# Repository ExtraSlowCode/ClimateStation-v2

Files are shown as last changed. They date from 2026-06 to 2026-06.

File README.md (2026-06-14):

# ClimateStation v2

A lightweight IoT climate monitor running on a Raspberry Pi Pico W. Reads temperature, humidity, and light level, then serves a terminal-aesthetic dashboard on the local network. No cloud dependency.

Soldered onto matrix board and housed in a custom 3D-printed case — designed to sit cleanly on a desk or shelf as a permanent fixture.

Successor to [ClimateStation](https://github.com/ExtraSlowCode/ClimateStation/tree/main) — reworked for local hosting, removed DataCake dependency.

---

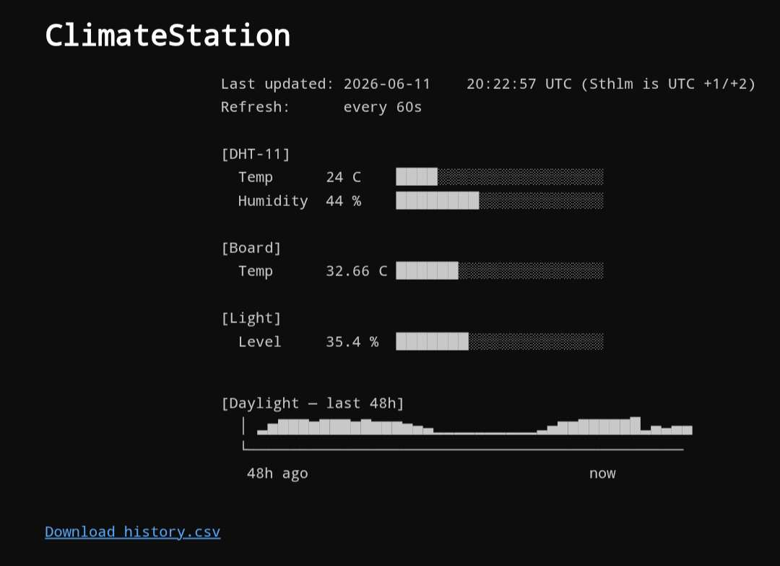
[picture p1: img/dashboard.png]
ClimateStation v2 dashboard

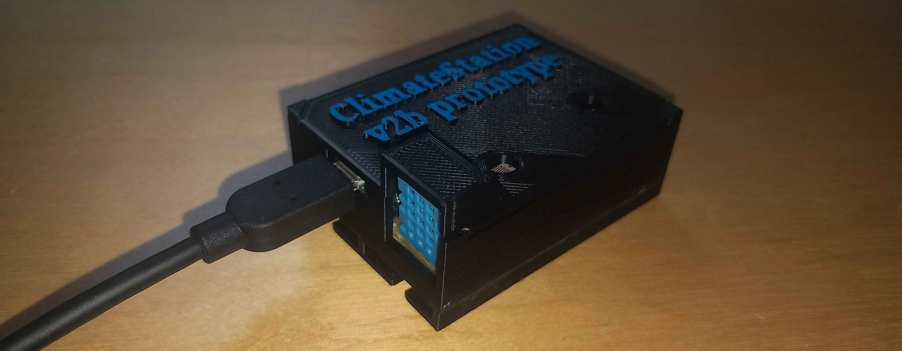
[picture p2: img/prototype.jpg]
ClimateStation v2 device


---

## Hardware

| Component | Purpose |
|---|---|
| Raspberry Pi Pico W | Microcontroller |
| DHT-11 | Temperature + humidity |
| Photo resistor (CdS 5mm) | Light level |
| On-board sensor (ADC4) | Secondary temperature |
| Green LED | Activity indicator |
| Matrix board | Permanent soldered assembly |

## Build

The circuit is soldered directly onto matrix board rather than using a breadboard, keeping the assembly compact and reliable. A custom case designed in TinkerCAD houses everything and is printed in standard PLA on an Ender 3.

Print settings:

- Filament: 1.75mm PLA
- Default supports
- Standard quality settings

The case design is included in `/case` as a `.stl` file.

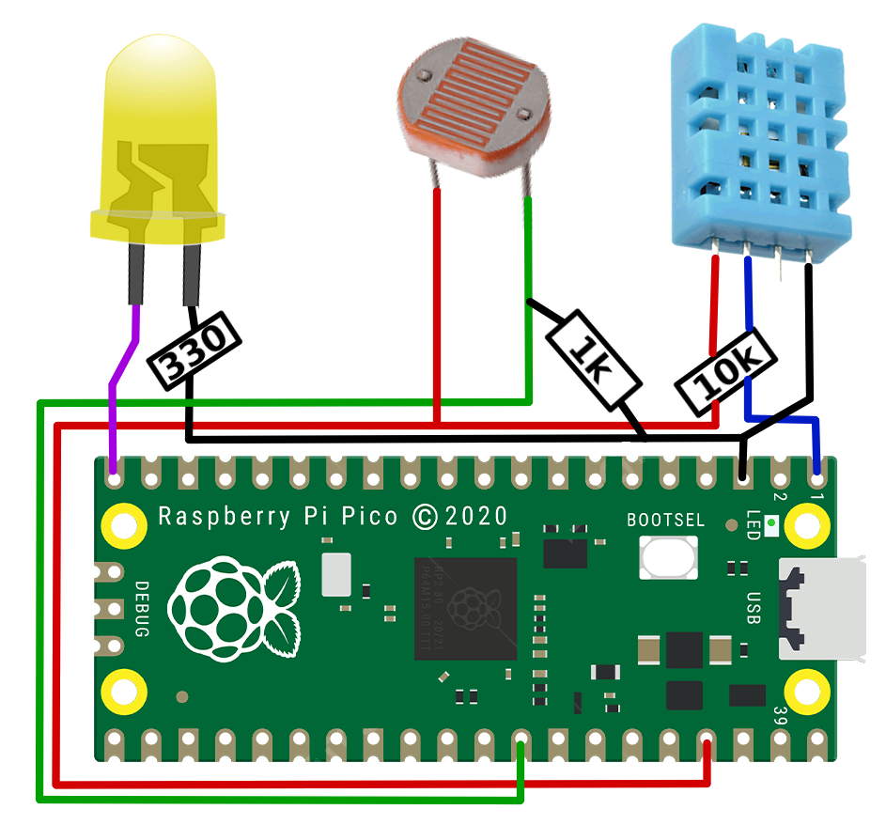
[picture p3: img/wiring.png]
Wiring diagram

Finished unit frontFinished unit back

## Features

- Local HTTP dashboard — no internet required beyond NTP sync for sensor function
- Terminal aesthetic: monospace, dark, ASCII bar charts
- Rolling CSV history with tiered retention:
  - Full resolution (10 min) for the last 7 days
  - Compressed (1 reading/hour) beyond that, ~5 months total
- `/history.csv` download endpoint
- Threaded: sensor loop and web server run independently
- Custom-designed case:
  - Easy to print at-home
  - Smart wall mount for screws

## Setup

1. Flash `micropython.uf2` onto the Pico W [micropython.org](https://micropython.org/download/RPI_PICO_W/)
2. Copy all files from `/src` to the Pico
3. Create `keys.py` with your WiFi credentials:

    ```python
    SSID = "your_network"
    PSWD = "your_password"
    ```

4. Power on — the Pico will blink the activity LED on startup, then connect
5. Find the assigned IP in the serial console and open it in a browser

## File Structure

```bash
src/
  main.py       # Startup, threading, sensor loop
  sensors.py    # DHT-11, board temp, light level reads
  server.py     # HTTP server, page rendering
  state.py      # Shared state with thread lock
  storage.py    # CSV read/write, tiered compression
  keys.py       # WiFi credentials (not committed)
case/
  case_v2.stl
```

## On AI Assistance

The software refactoring; restructuring the original monolithic script into a modular, threaded codebase, was done with Claude as a development aid. The sensor hardware, physical build, wiring, case design, and original project are entirely my own work. I've kept the AI use here because the task was largely mechanical restructuring rather than problem solving, and the result was reviewed and understood before being deployed. It's disclosed here in the interest of transparency.

## Notes

- Timestamps are UTC — Stockholm is UTC+1 (CET) or UTC+2 (CEST)
- The board LED stays on as a WiFi connection indicator, and blinks while attempting to connect.
- `keys.py` is excluded from version control to keep it out of commits

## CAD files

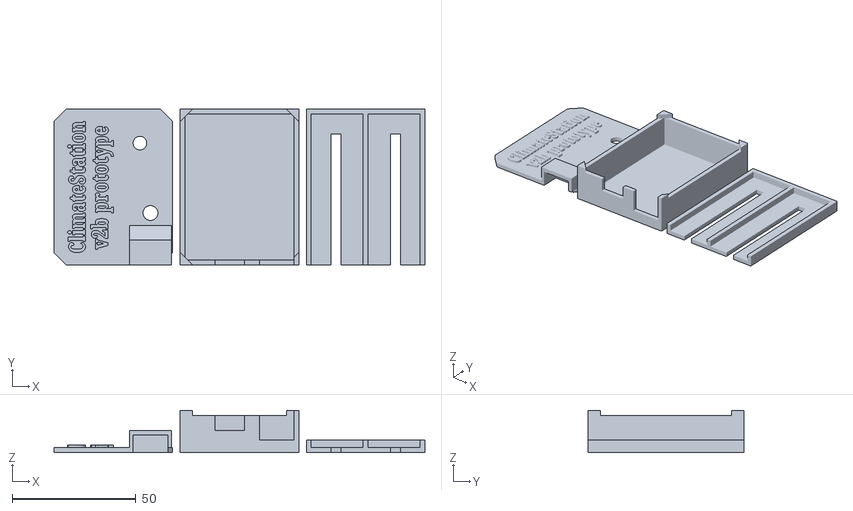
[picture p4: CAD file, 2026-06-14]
case/case_v2.stl
150.0 x 63.0 x 17.0

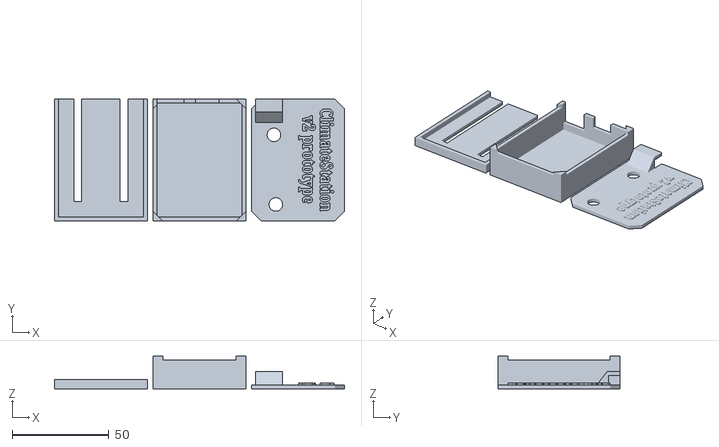
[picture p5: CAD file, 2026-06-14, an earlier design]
case/case_v1.stl
150.0 x 63.0 x 17.0

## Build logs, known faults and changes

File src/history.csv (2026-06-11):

timestamp | temp_dht | humidity | temp_board | light_level
2026-06-08T09:51:38 | 25 | 51 | 32.19 | 18.6
2026-06-08T09:53:57 | 25 | 48 | 30.32 | 21.6
2026-06-08T09:58:18 | 25 | 48 | 33.6 | 32.7
2026-06-08T09:58:51 | 25 | 48 | 33.6 | 35.2
2026-06-10T09:34:07 | 24 | 53 | 32.66 | 44.7
2026-06-10T09:34:40 | 24 | 52 | 32.66 | 44.6
2026-06-10T09:35:13 | 24 | 52 | 32.66 | 44.4
2026-06-10T09:36:32 | 23 | 50 | 32.19 | 45.2
2026-06-10T09:39:10 | 24 | 51 | 30.32 | 68.0
2026-06-10T09:49:12 | 24 | 51 | 41.09 | 85.5
2026-06-10T10:09:17 | 37 | 20 | 40.62 | 83.7
2026-06-10T10:19:19 | 37 | 20 | 35.47 | 70.8
2026-06-10T10:29:22 | 36 | 20 | 34.53 | 72.1
2026-06-10T10:39:24 | 34 | 23 | 33.13 | 64.6
2026-06-10T10:49:27 | 32 | 26 | 32.66 | 71.6
2026-06-10T10:59:29 | 29 | 31 | 32.19 | 63.2
2026-06-10T11:09:32 | 27 | 37 | 32.19 | 67.5
2026-06-10T11:19:34 | 25 | 41 | 35.47 | 88.4
2026-06-10T11:29:37 | 25 | 44 | 34.53 | 84.3
2026-06-10T11:39:39 | 25 | 45 | 33.6 | 70.8
2026-06-10T11:49:42 | 25 | 46 | 32.19 | 61.5
2026-06-10T11:59:44 | 25 | 46 | 31.73 | 52.8
2026-06-10T12:09:47 | 24 | 47 | 32.19 | 81.6
2026-06-10T12:19:49 | 24 | 47 | 31.73 | 73.2
2026-06-10T12:29:52 | 24 | 48 | 31.26 | 64.3
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

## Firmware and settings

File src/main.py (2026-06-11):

import _thread
import network
import ntptime
import machine
from time import sleep, localtime
from state import state
from sensors import dht_read, board_temp_read, light_level_read
from storage import append_reading, read_csv
from server import start_server
import keys


POLL_INTERVAL = 600  # 10 minutes


# Pin setup
send_led  = machine.Pin(15, machine.Pin.OUT)
board_led = machine.Pin("LED", machine.Pin.OUT)


def lit(pin, on):
    pin.on() if on else pin.off()


def timestamp_iso():
    t = localtime()
    return f"{t[0]}-{t[1]:02d}-{t[2]:02d}T{t[3]:02d}:{t[4]:02d}:{t[5]:02d}"

def timestamp_display():
    t = localtime()
    return f"{t[0]}-{t[1]:02d}-{t[2]:02d}\t{t[3]:02d}:{t[4]:02d}:{t[5]:02d} UTC (Sthlm is UTC +1/+2)"


def connect_wifi():
    wlan = network.WLAN(network.STA_IF)
    wlan.active(True)
    network.hostname("climatestation")
    wlan.connect(keys.SSID, keys.PSWD)
    while not wlan.isconnected():
        lit(board_led, True)
        print("Connecting to WiFi...")
        sleep(1)
        lit(board_led, False)
    ip = wlan.ifconfig()[0]
    print(f"Connected to {keys.SSID} — {ip}")
    return ip


def http_get_portal():
    import socket, time
    url = "http://detectportal.firefox.com/"
    _, _, host, path = url.split("/", 3)
    addr = socket.getaddrinfo(host, 80)[0][-1]
    s = socket.socket()
    s.connect(addr)
    s.send(bytes(f"GET /{path} HTTP/1.0\r\nHost: {host}\r\n\r\n", "utf8"))
    time.sleep(1)
    s.recv(10000)
    s.close()


def ensure_wifi():
    wlan = network.WLAN(network.STA_IF)
    if not wlan.isconnected():
        print("WiFi lost — reconnecting...")
        wlan.disconnect()
        wlan.connect(keys.SSID, keys.PSWD)
        for _ in range(20):
            if wlan.isconnected():
                print("WiFi restored —", wlan.ifconfig()[0])
                return True
            sleep(1)
        print("WiFi reconnect failed — rebooting")
        machine.reset()
        return False
    return True


def startup():
    lit(send_led, False)
    lit(board_led, False)

    # Blink on startup
    for i in range(6):
        lit(send_led, i % 2 == 0)
        sleep(0.5)

    connect_wifi()
    http_get_portal()       # WiFi stability fix
    lit(board_led, True)    # WiFi up indicator

    try:
        ntptime.settime()
        print("NTP sync OK —", timestamp_display())
    except Exception as e:
        print("NTP sync failed:", e)


def sensor_loop():
    while True:
        ensure_wifi()
        temp_dht, humidity  = dht_read()
        temp_board          = board_temp_read()
        light               = light_level_read()
        ts_iso     = timestamp_iso()
        ts_display = timestamp_display()

        if None not in (temp_dht, humidity, temp_board, light):
            state.update(temp_dht, humidity, temp_board, light, ts_display)
            append_reading(ts_iso, temp_dht, humidity, temp_board, light)
            
            lit(send_led, True)
            print(f"READ data: DHT {temp_dht}C, {humidity}%\t board {temp_board}C\t light {light}\t at:{ts_display}")
            sleep(0.1)
            lit(send_led, False)
        else:
            print(f"{ts_display} — partial read failure, skipping append")

        sleep(POLL_INTERVAL)


# Boot
startup()

# Server on second thread, sensor loop on main
_thread.start_new_thread(start_server, (state, read_csv, "0.0.0.0", 80))
sensor_loop()

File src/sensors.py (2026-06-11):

from machine import Pin, ADC
import dht, time

# Pin definitions
DHT_PIN       = 0
PHOTO_RES_PIN = 27  # ADC pin

# Sensor init
dht_sensor        = dht.DHT11(Pin(DHT_PIN))
photo_res         = ADC(PHOTO_RES_PIN)
board_temp_sensor = ADC(4)


def dht_read():
    try:
        time.sleep(2)
        dht_sensor.measure()
        return dht_sensor.temperature(), dht_sensor.humidity()
    except Exception as e:
        print("DHT11 read error:", e)
        return None, None


def board_temp_read():
    try:
        voltage    = board_temp_sensor.read_u16() * (3.3 / 65535.0)
        temp       = 27 - (voltage - 0.706) / 0.001721
        return round(temp, 2)
    except Exception as e:
        print("Board temp read error:", e)
        return None


def light_level_read():
    try:
        return round(photo_res.read_u16() / 65535 * 100, 1)
    except Exception as e:
        print("Light level read error:", e)
        return None

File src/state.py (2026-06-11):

import _thread

class SharedState:
    def __init__(self):
        self.lock = _thread.allocate_lock()
        self.temp_dht    = 0.0
        self.humidity    = 0
        self.temp_board  = 0.0
        self.light_level = 0.0
        self.last_updated = "never"

    def update(self, temp_dht, humidity, temp_board, light_level, timestamp):
        with self.lock:
            self.temp_dht    = temp_dht
            self.humidity    = humidity
            self.temp_board  = temp_board
            self.light_level = light_level
            self.last_updated = timestamp

    def snapshot(self):
        with self.lock:
            return {
                "temp_dht":    self.temp_dht,
                "humidity":    self.humidity,
                "temp_board":  self.temp_board,
                "light_level": self.light_level,
                "last_updated": self.last_updated
            }

# Single instance, imported everywhere
state = SharedState()

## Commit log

2026-06-11 Initial upload
    [history.csv]
2026-06-14 upload prototype case, update README
    [case_v1.stl, case_v2.stl]
